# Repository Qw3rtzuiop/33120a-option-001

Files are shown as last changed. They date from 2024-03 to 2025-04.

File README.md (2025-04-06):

# 33120a-option-001
External reference frequency option for the HP/Agilent/Keysight 33120a arbitrary function generator

<span style="color:red">The calibration can fail with "value range" error. I solved it by repeating the calibration 86 multiple times changing the readout frequency in small and bigger steps.</span>

The ocxo is a used Vectron C4550A1-0213 (10 MHz, 5V).

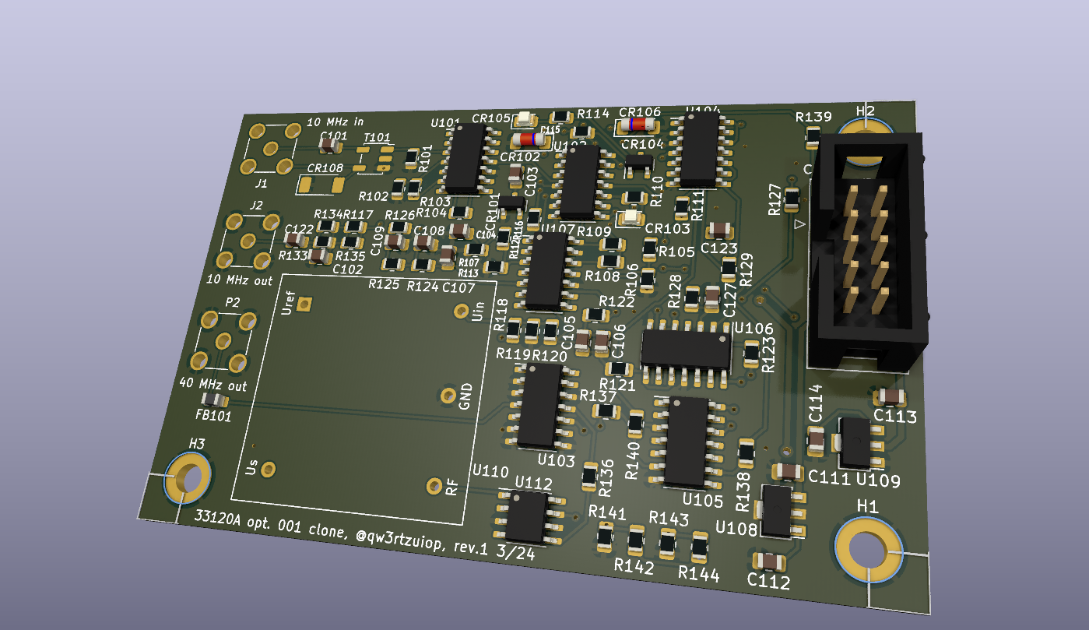
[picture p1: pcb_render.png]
3d Render of the PCB

Kicad 3d render pic of the rev. 1 PCB.

installed pcb

The PCB is mounted on the side. You need to drill holes into the metal to mount the PCB. The pics show the rev. 0 with two bodge wires. 

installed pcb

Suitable isolated BNC jacks are Amphenol 112252.

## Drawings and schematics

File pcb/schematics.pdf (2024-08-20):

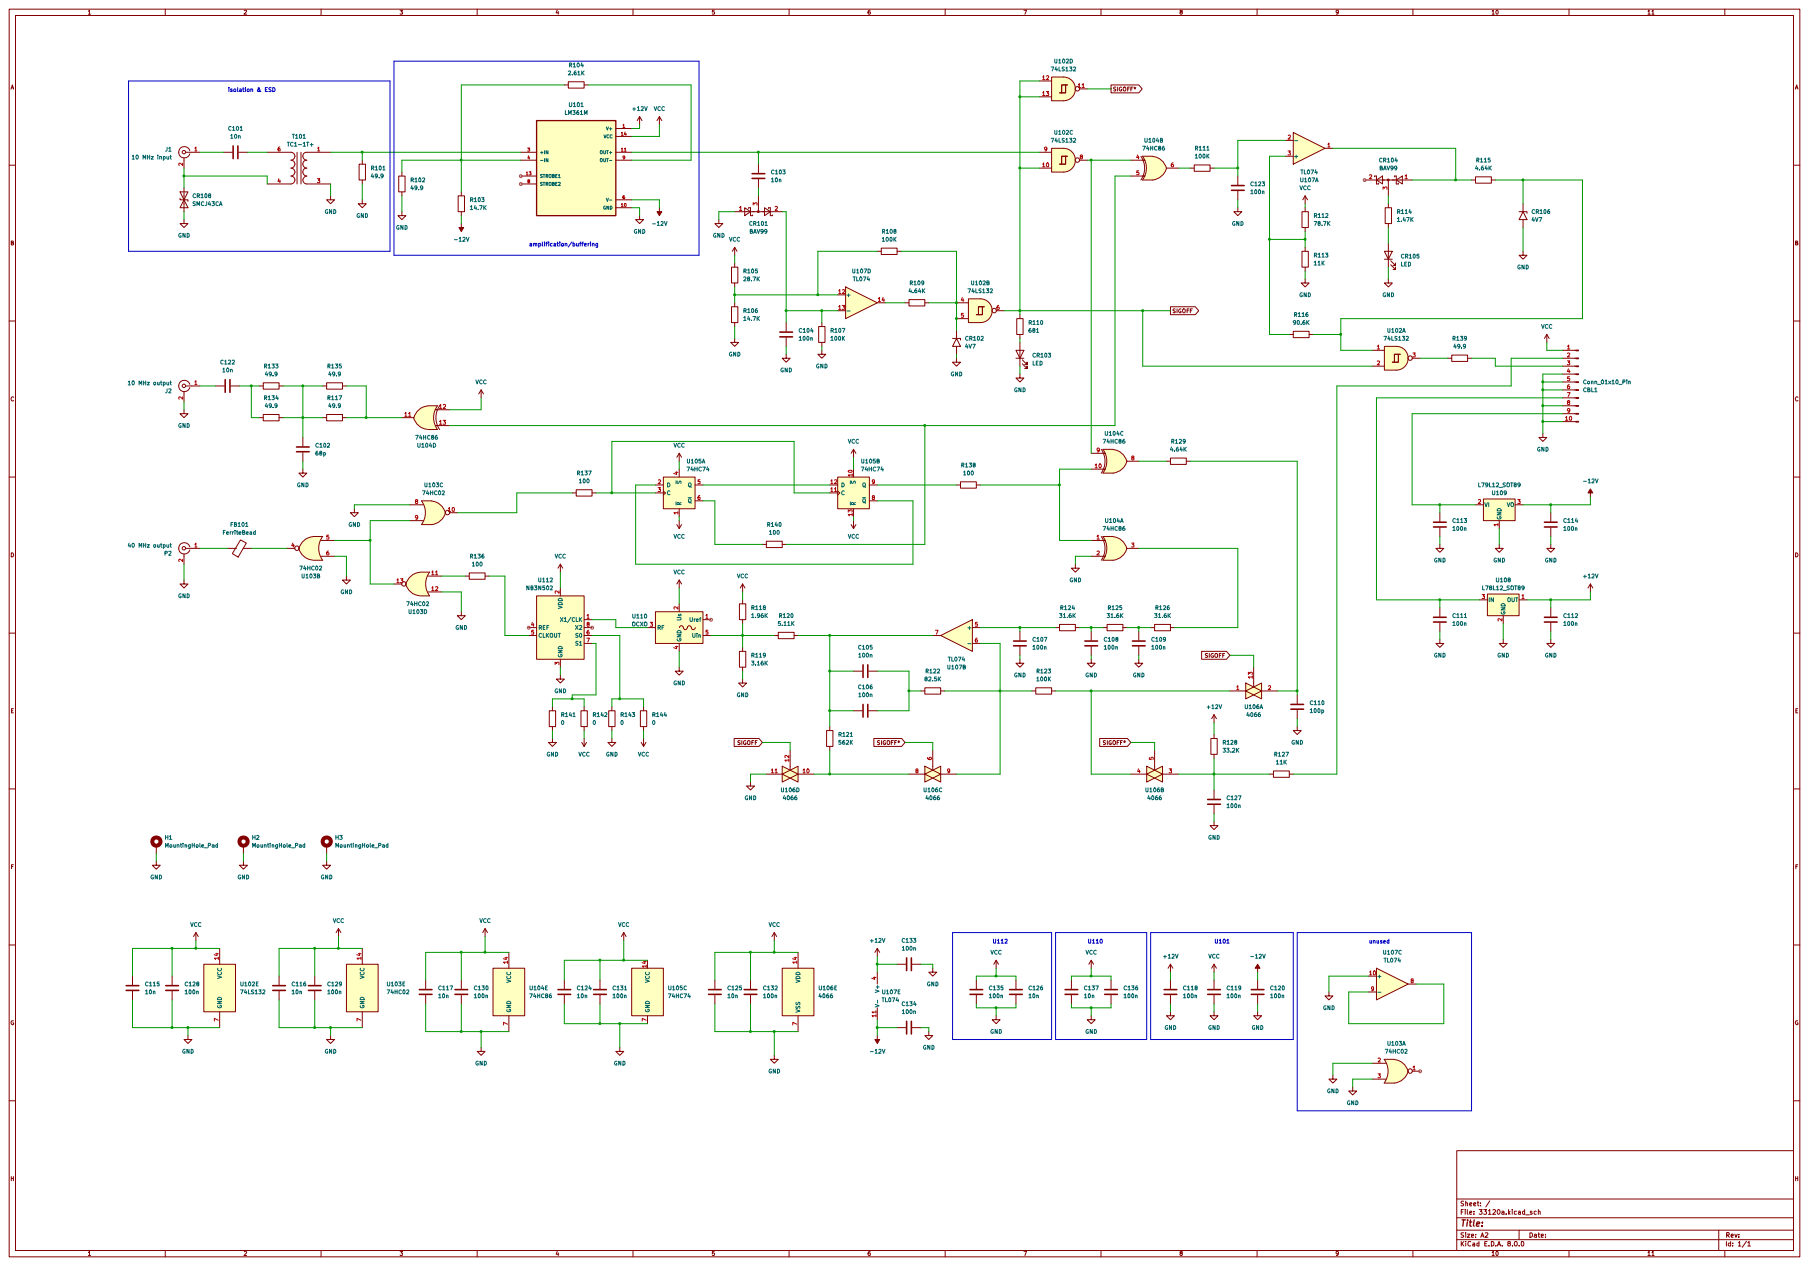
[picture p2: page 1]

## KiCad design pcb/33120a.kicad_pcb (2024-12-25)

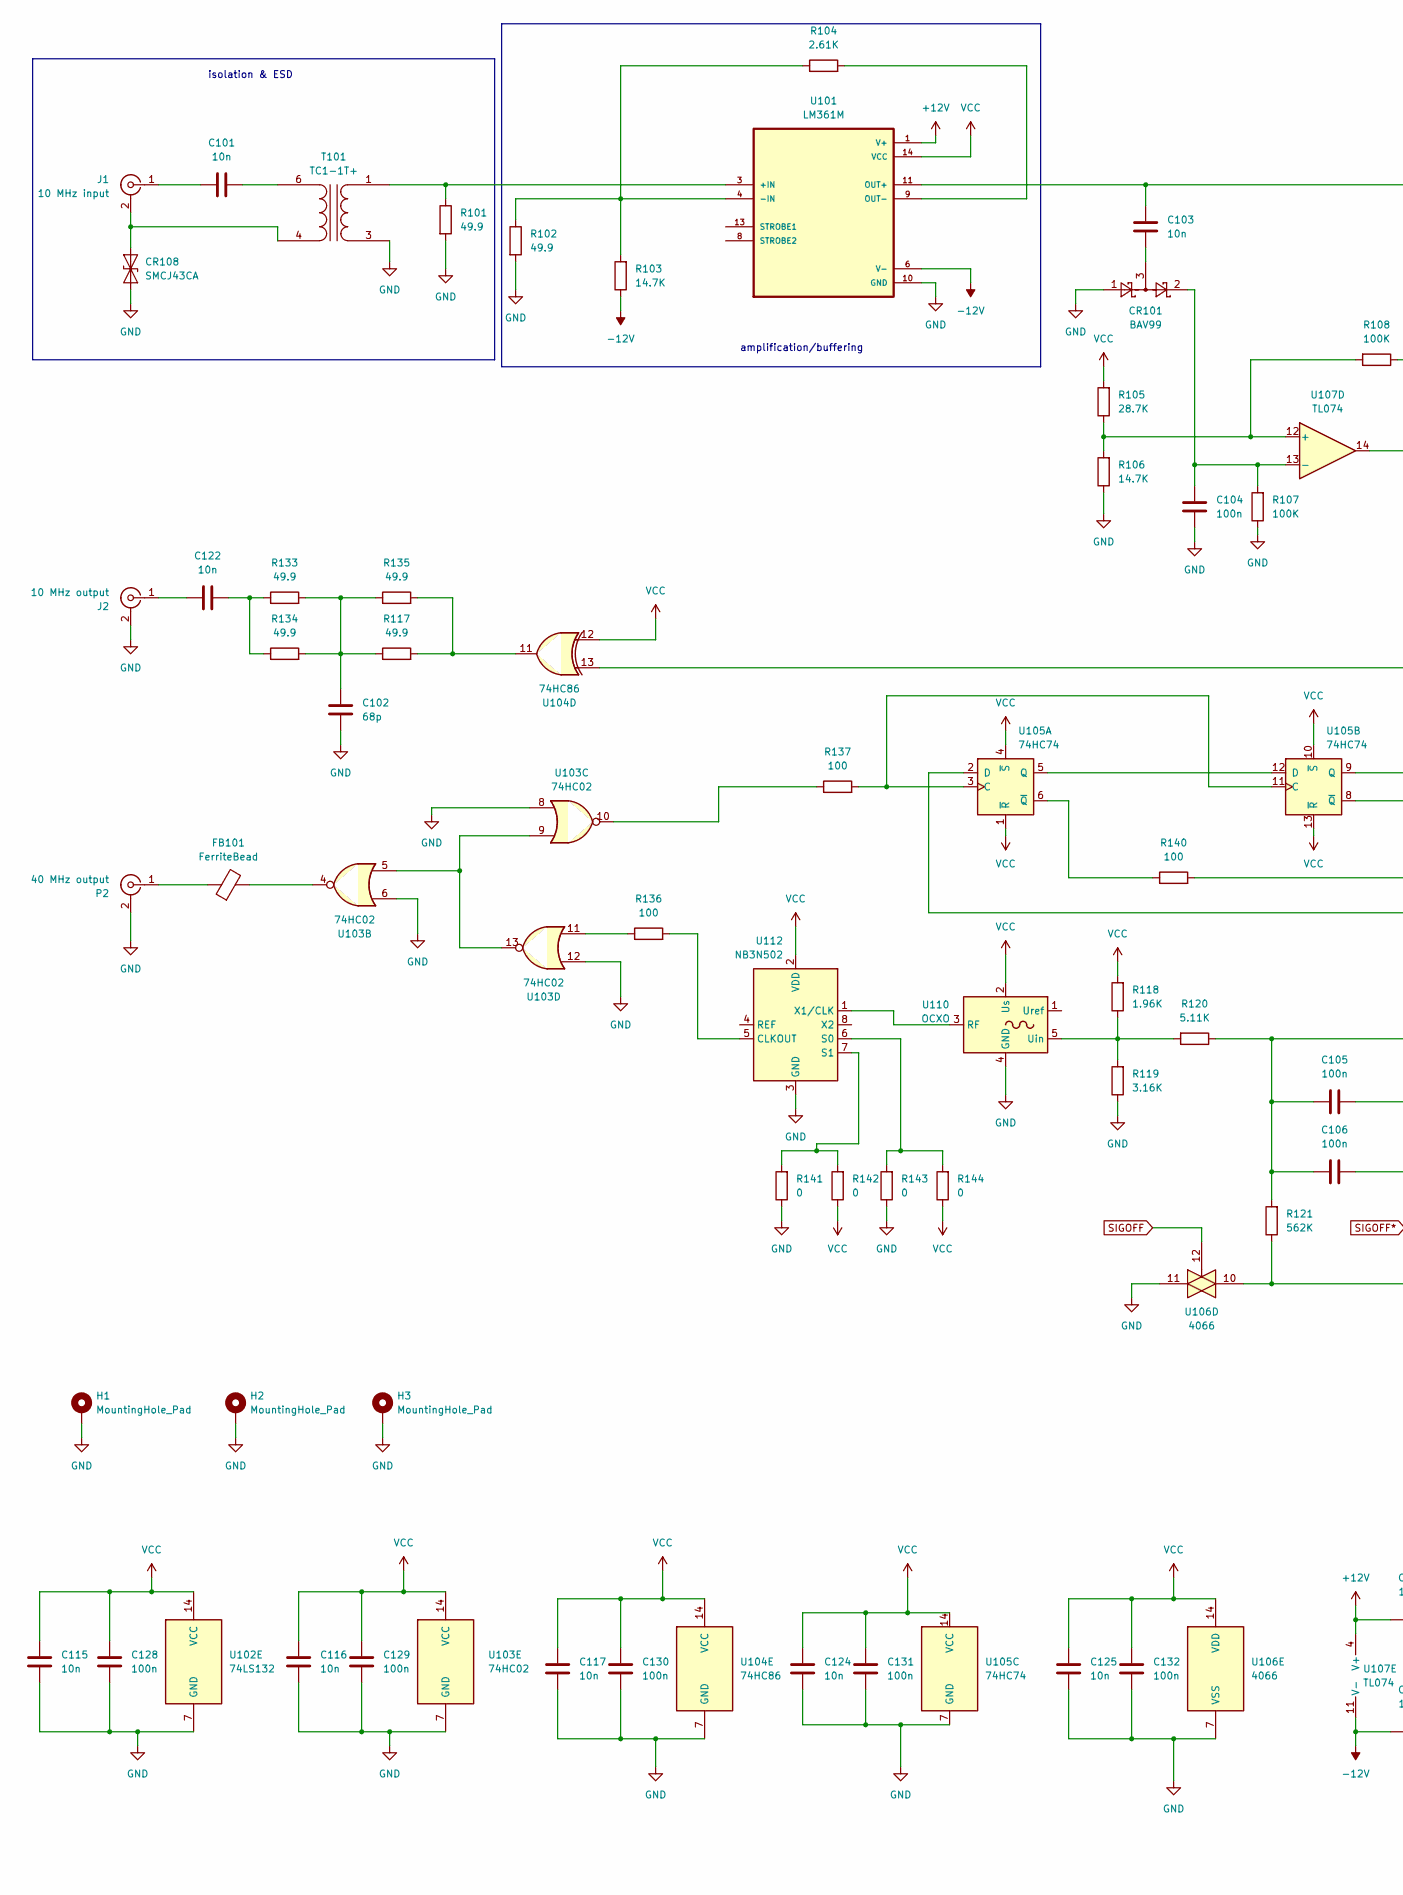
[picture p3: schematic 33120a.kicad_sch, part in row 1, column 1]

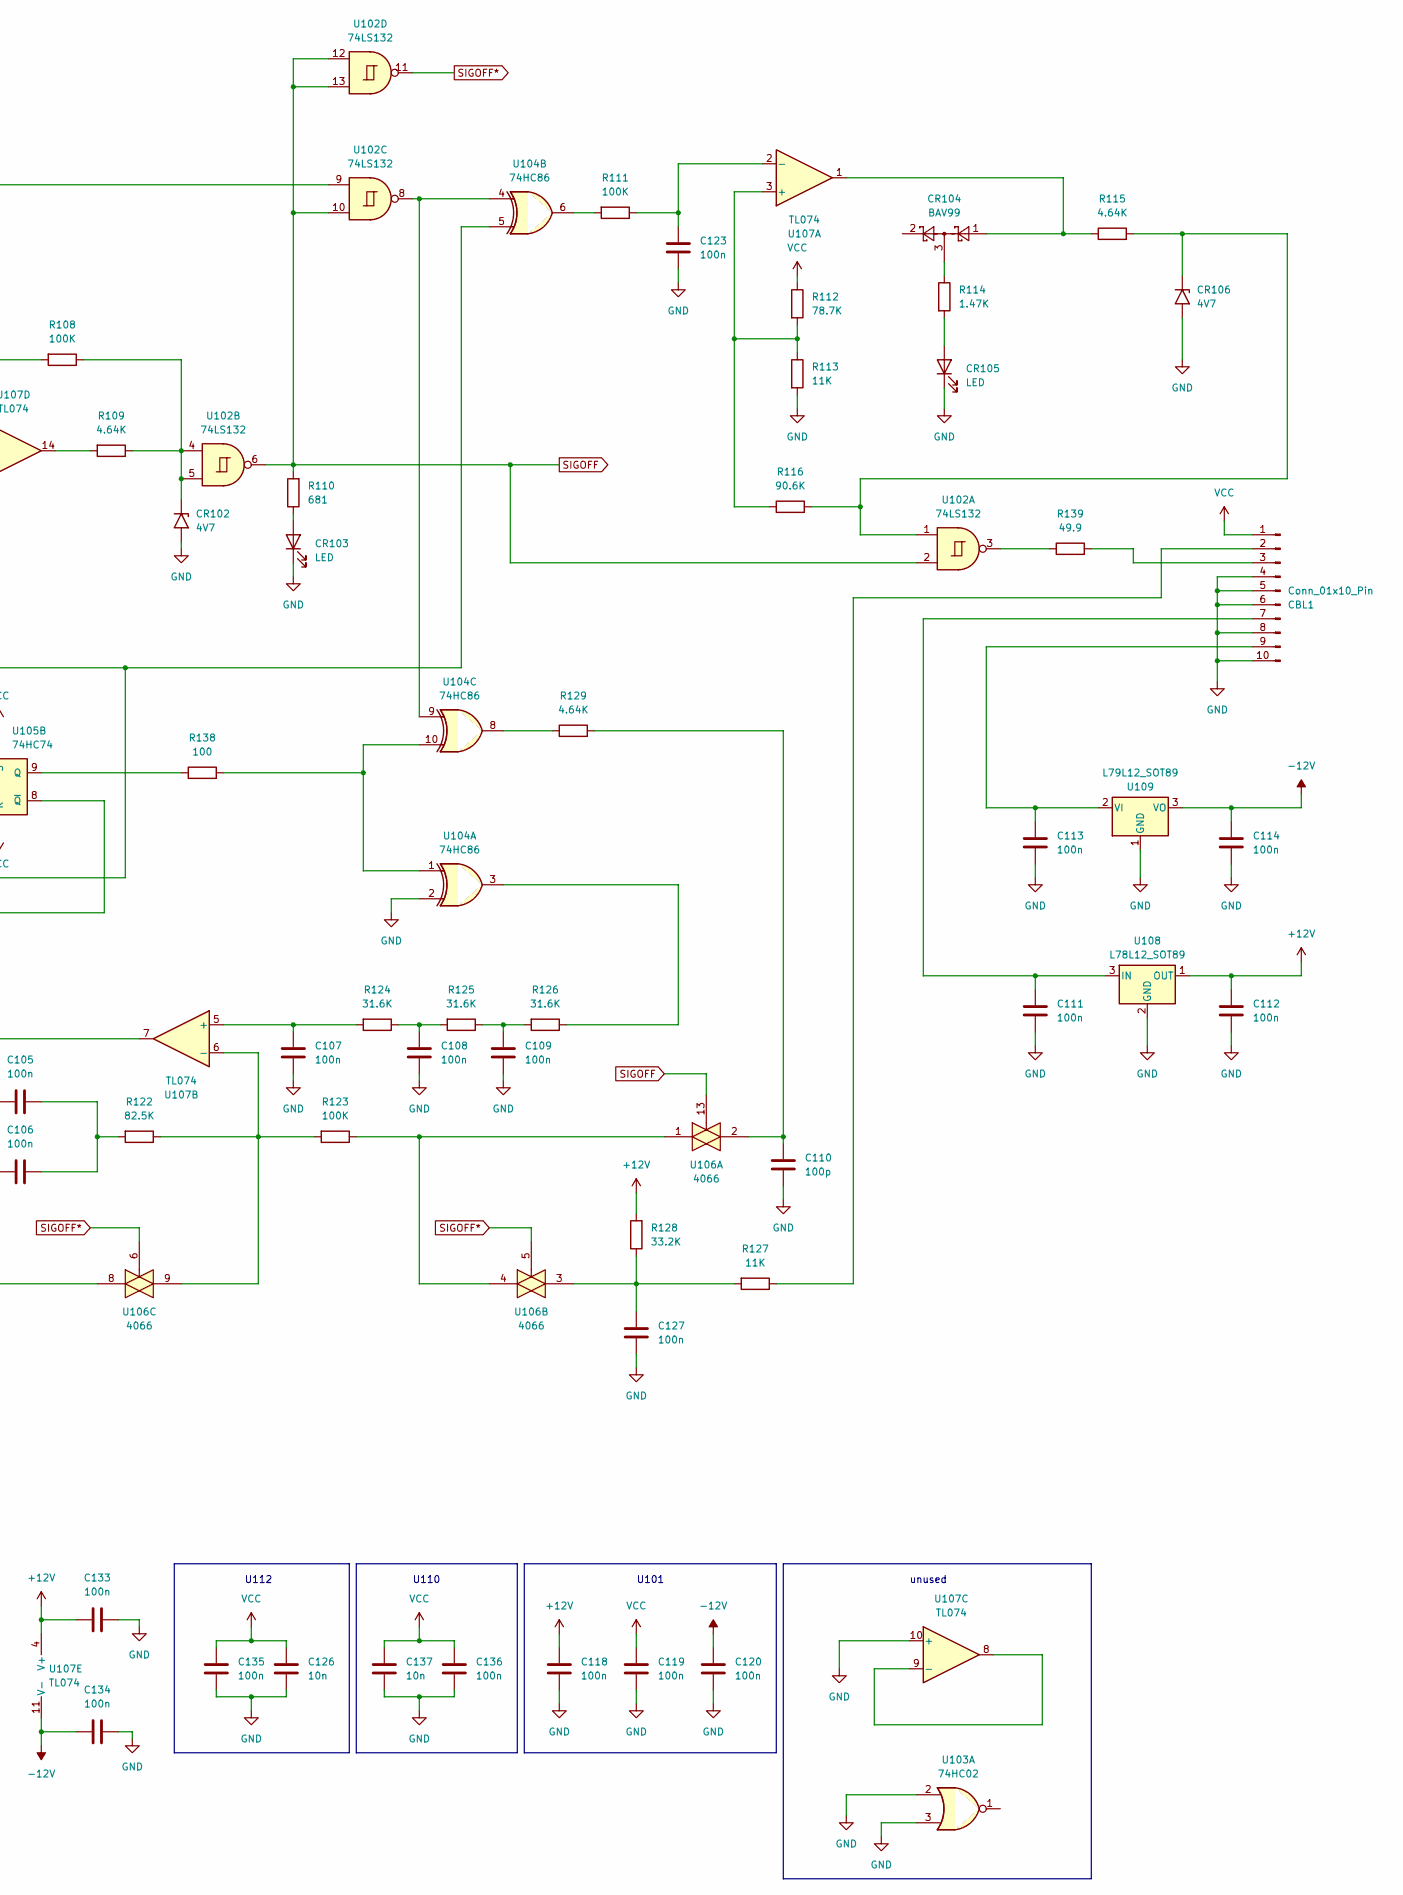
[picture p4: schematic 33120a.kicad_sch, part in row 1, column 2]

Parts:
C101, C103, C115, C116, C117, C122, C124, C125, C126, C137: 10n; C_0805_2012Metric
C102: 68p; C_0805_2012Metric
C104, C105, C106, C107, C108, C109, C111, C112, C113, C114, C118, C119, C120, C123, C127, C128, C129, C130, C131, C132, C133, C134, C135, C136: 100n; C_0805_2012Metric
C110: 100p; C_0805_2012Metric
CBL1: Conn_01x10_Pin; IDC-Header_2x05_P2.54mm_Vertical
CR101, CR104: BAV99; SOT-23
CR102, CR106: 4V7; D_MiniMELF
CR103, CR105: LED; LED_0805_2012Metric
CR108: SMCJ43CA; D_SOD-128
FB101: FerriteBead; L_0805_2012Metric
H1, H2, H3: MountingHole_Pad; MountingHole_3.2mm_M3_DIN965_Pad_TopBottom
J1: 10 MHz input; SMA_Amphenol_901-144_Vertical
J2: 10 MHz output; SMA_Amphenol_901-144_Vertical
P2: 40 MHz output; SMA_Amphenol_901-144_Vertical
R101, R102, R117, R133, R134, R135, R139: 49.9; R_0805_2012Metric
R103, R106: 14.7K; R_0805_2012Metric
R104: 2.61K; R_0805_2012Metric
R105: 28.7K; R_0805_2012Metric
R107, R108, R111, R123: 100K; R_0805_2012Metric
R109, R115, R129: 4.64K; R_0805_2012Metric
R110: 681; R_0805_2012Metric
R112: 78.7K; R_0805_2012Metric
R113, R127: 11K; R_0805_2012Metric
R114: 1.47K; R_0805_2012Metric
R116: 90.6K; R_0805_2012Metric
R118: 1.96K; R_0805_2012Metric
R119: 3.16K; R_0805_2012Metric
R120: 5.11K; R_0805_2012Metric
R121: 562K; R_0805_2012Metric
R122: 82.5K; R_0805_2012Metric
R124, R125, R126: 31.6K; R_0805_2012Metric
R128: 33.2K; R_0805_2012Metric
R136, R137, R138, R140: 100; R_0805_2012Metric
R141, R142, R143, R144: 0; R_0805_2012Metric
T101: TC1-1T+; Transformer_MiniCircuits_AT224-1A
U101: LM361M; SOIC-14_3.9x8.7mm_P1.27mm
U102: 74LS132; SOIC-14_3.9x8.7mm_P1.27mm
U103: 74HC02; SOIC-14_3.9x8.7mm_P1.27mm
U104: 74HC86; SOIC-14_3.9x8.7mm_P1.27mm
U105: 74HC74; SOIC-14_3.9x8.7mm_P1.27mm
U106: 4066; SOIC-14_3.9x8.7mm_P1.27mm
U107: TL074; SOIC-14_3.9x8.7mm_P1.27mm
U108: L78L12_SOT89; SOT-89-3
U109: L79L12_SOT89; SOT-89-3
U110: OCXO; Oscillator_OCXO_Morion_MV317
U112: NB3N502; SOIC-8_3.9x4.9mm_P1.27mm

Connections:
+12V: C112.1, C118.1, C133.1, R128.2, U101.1 (V+), U107.4 (V+), U108.1 (OUT)
-12V: C114.1, C120.1, C134.1, R103.1, U101.6 (V-), U107.11 (V-), U109.3 (VO)
GND: C102.1, C104.2, C107.1, C108.1, C109.1, C110.1, C111.2, C112.2, C113.2, C114.2, C115.2, C116.2, C117.2, C118.2, C119.2, C120.2, C123.2, C124.2, C125.2, C126.2, C127.1, C128.2, C129.2, C130.2, C131.2, C132.2, C133.2, C134.2, C135.2, C136.2, C137.2, CBL1.4, CBL1.5, CBL1.6, CBL1.8, CBL1.10, CR101.1, CR102.2 (A2), CR103.1 (K), CR105.1 (K), CR106.2 (A2), CR108.1 (A1), H1.1, H2.1, H3.1, J2.2 (Ext), P2.2 (Ext), R101.2, R102.2, R106.1, R107.1, R113.2, R119.1, R141.1, R143.1, T101.3 (SA), U101.10 (GND), U102.7 (GND), U103.2, U103.3, U103.6, U103.7 (GND), U103.8, U103.12, U104.2, U104.7 (GND), U105.7 (GND), U106.7 (VSS), U106.11, U107.10 (+), U108.2 (GND), U109.1 (GND), U110.4 (GND), U112.3 (GND)
unnamed: C102.2, R117.1, R133.2, R134.2, R135.1
unnamed: C103.2, CR101.3
unnamed: C105.1, C106.1, R120.1, R121.2, U107.7
unnamed: C105.2, C106.2, R122.2
unnamed: C108.2, R124.1, R125.2
unnamed: C109.2, R125.1, R126.2
unnamed: C110.2, R129.2, U106.2
unnamed: C122.2, R133.1, R134.1
unnamed: C127.2, R127.2, R128.1, U106.3
unnamed: CBL1.2, R127.1
unnamed: CBL1.3, R139.2
unnamed: C111.1, CBL1.7, U108.3 (IN)
unnamed: C113.1, CBL1.9, U109.2 (VI)
unnamed: CR102.1 (A1), R108.1, R109.1, U102.4, U102.5
unnamed: CR103.2 (A), R110.1
unnamed: CR104.1, R115.1, U107.1
unnamed: CR104.3, R114.1
unnamed: CR105.2 (A), R114.2
unnamed: CR106.1 (A1), R115.2, R116.2, U102.1
unnamed: CR108.2 (A2), J1.2 (Ext), T101.4 (AB)
unnamed: FB101.2, U103.4
unnamed: C101.1, J1.1 (In)
unnamed: C122.1, J2.1 (In)
unnamed: FB101.1, P2.1 (In)
unnamed: R109.2, U107.14
unnamed: R111.2, U104.6
unnamed: R117.2, R135.2, U104.11
unnamed: R121.1, U106.8, U106.10
unnamed: R123.1, U106.1, U106.4
unnamed: R126.1, U104.3
unnamed: R129.1, U104.8
unnamed: R136.1, U103.11
unnamed: R137.1, U103.10
unnamed: R138.2, U104.1, U104.10
unnamed: R139.1, U102.3
unnamed: R140.2, U104.5, U104.13
unnamed: C101.2, T101.6 (AA)
unnamed: R101.1, T101.1 (SB), U101.3 (+IN)
unnamed: R102.1, R103.2, R104.1, U101.4 (-IN)
unnamed: C103.1, U101.11 (OUT+), U102.9
unnamed: R104.2, U101.9 (OUT-)
unnamed: U102.8, U104.4, U104.9
unnamed: U103.5, U103.9, U103.13
unnamed: R137.2, U105.3 (C), U105.11 (C)
unnamed: U105.2 (D), U105.8 (~Q)
unnamed: U105.5 (Q), U105.12 (D)
unnamed: R140.1, U105.6 (~Q)
unnamed: R138.1, U105.9 (Q)
unnamed: R112.2, R113.1, R116.1, U107.3 (+)
unnamed: C123.1, R111.1, U107.2 (-)
unnamed: C107.2, R124.2, U107.5 (+)
unnamed: R122.1, R123.2, U106.9, U107.6 (-)
unnamed: U107.8, U107.9 (-)
unnamed: R105.1, R106.2, R108.2, U107.12 (+)
unnamed: C104.1, CR101.2, R107.2, U107.13 (-)
unnamed: U110.3 (RF), U112.1 (X1/CLK)
unnamed: R118.1, R119.2, R120.2, U110.5 (Uin)
unnamed: R136.2, U112.5 (CLKOUT)
unnamed: R143.2, R144.2, U112.6 (S0)
unnamed: R141.2, R142.2, U112.7 (S1)
SIGOFF: R110.2, U102.2, U102.6, U102.10, U102.12, U102.13, U106.12, U106.13
SIGOFF*: U102.11, U106.5, U106.6
VCC: C115.1, C116.1, C117.1, C119.1, C124.1, C125.1, C126.1, C128.1, C129.1, C130.1, C131.1, C132.1, C135.1, C136.1, C137.1, CBL1.1, R105.2, R112.1, R118.2, R142.1, R144.1, U101.14 (VCC), U102.14 (VCC), U103.14 (VCC), U104.12, U104.14 (VCC), U105.1 (~R), U105.4 (~S), U105.10 (~S), U105.13 (~R), U105.14 (VCC), U106.14 (VDD), U110.2 (Us), U112.2 (VDD)

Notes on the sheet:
U101
U112
isolation & ESD
amplification/buffering
unused
U110

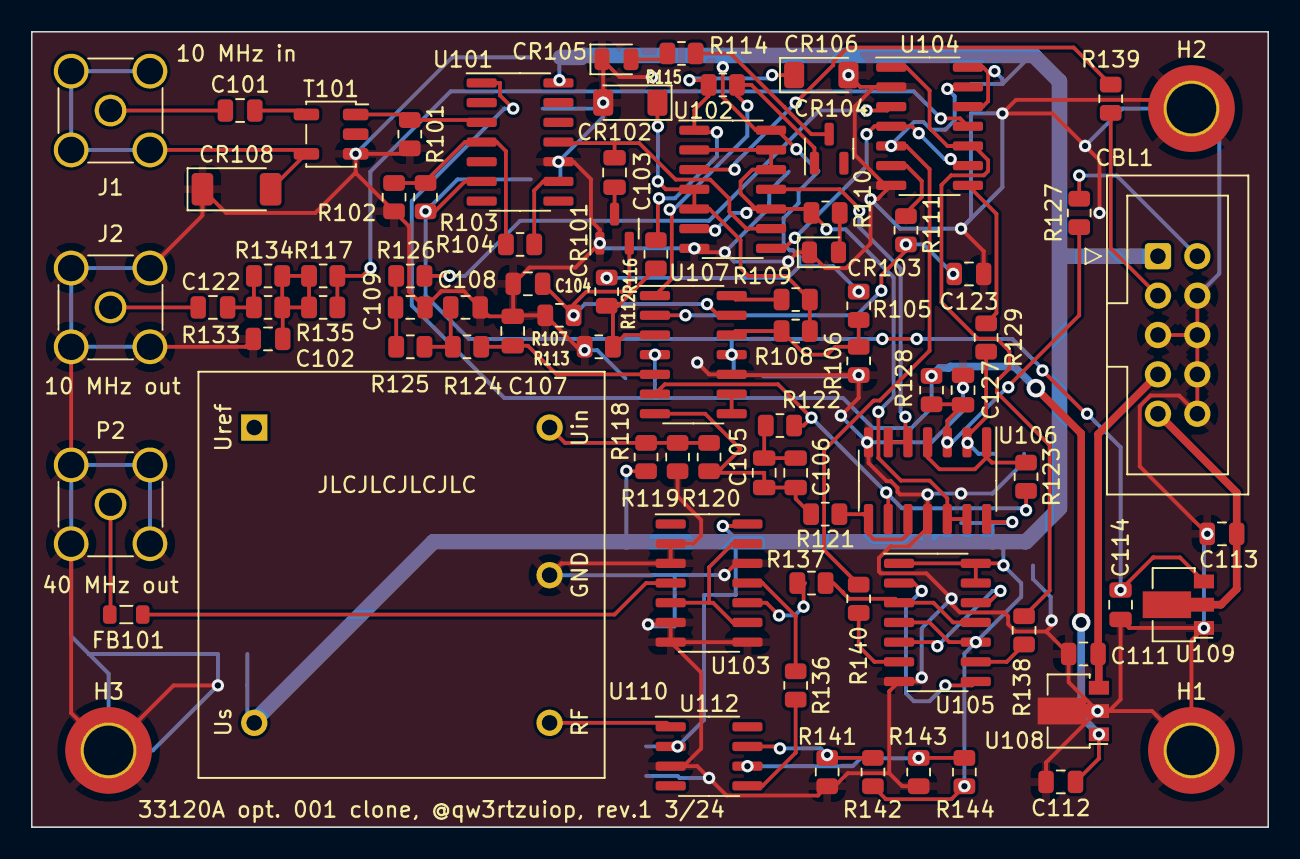
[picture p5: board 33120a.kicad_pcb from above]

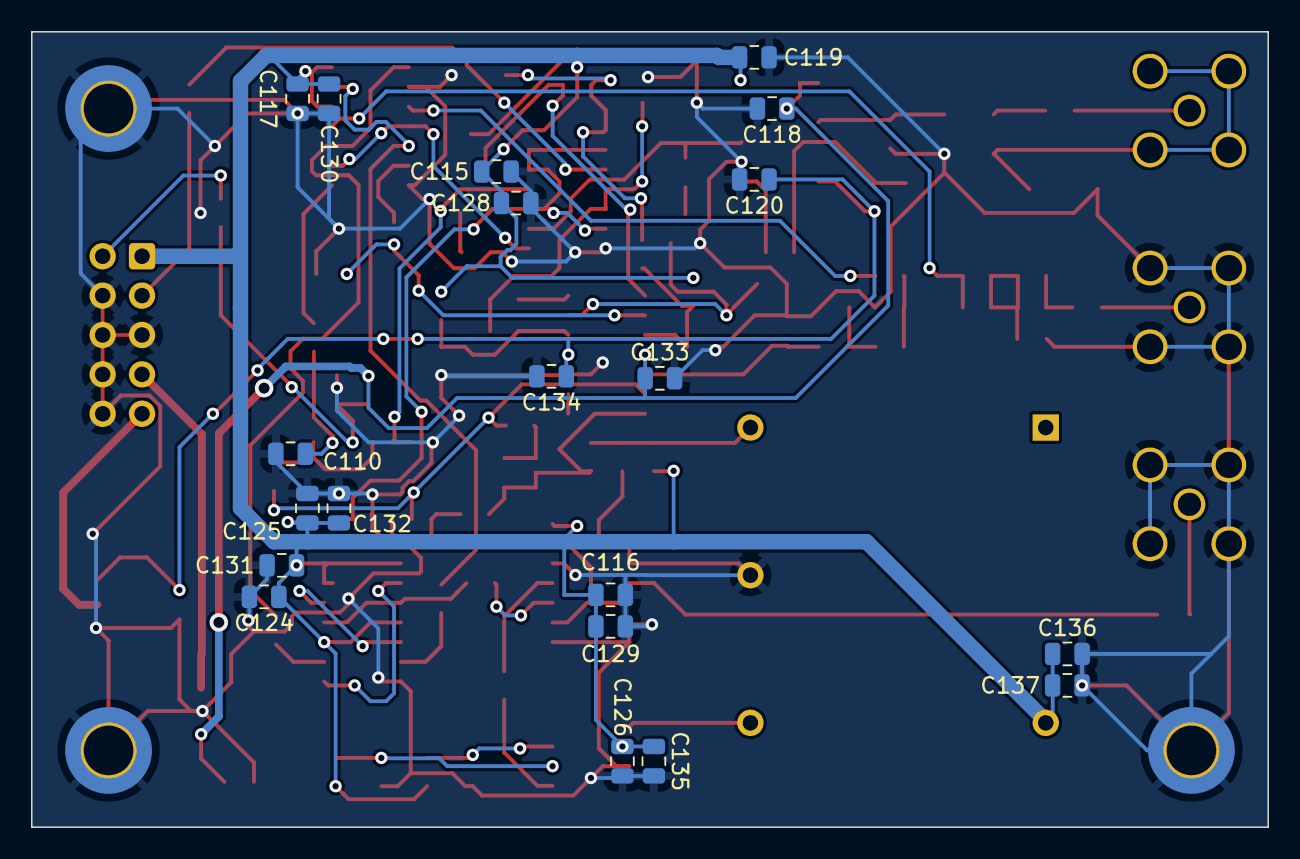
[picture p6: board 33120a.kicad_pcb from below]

Board: 2 copper layers, 79.8 x 51.3 mm, 104 parts (20 on the bottom side), 66 nets.

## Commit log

2024-03-08 rev. 1
    [33120a-B_Cu.gbr, 33120a-B_Mask.gbr, 33120a-B_Paste.gbr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]
2024-08-20 added info
    [33120a.kicad_sch]
2024-12-25 silkscreen update
    [33120a-B_Cu.gbr, 33120a-B_Mask.gbr, 33120a-B_Paste.gbr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]
